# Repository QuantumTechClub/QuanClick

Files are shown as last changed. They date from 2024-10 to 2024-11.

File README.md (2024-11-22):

Heading Title Image, QuanClick logo on the left, Quantum Technology Club logo on the right

## Table of Contents
1. [Getting Started](#getting-started)
   - [Quickstart](#quickstart-i-dont-want-to-read-tutorials)
   - [In More Detail](#in-more-detail)
     - [Setting up your development environment](#setting-up-your-development-environment)
     - [Programming your QuanClick](#programming-your-quanclick)
2. [Customization](#customization)

## What
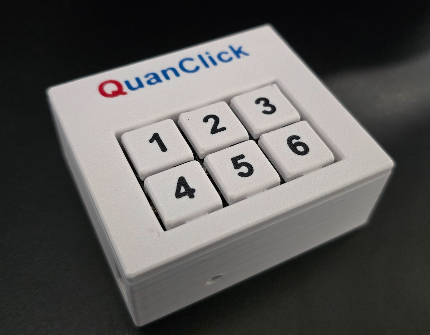
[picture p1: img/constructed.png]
A photograph of a completed QuanClick unit


QuanClick is a six-button macro keyboard (and HID) device, designed to be low cost, easy to assemble, and easy to customize.

## Why
To support and promote S.T.E.A.M. (Science, Technology, Engineering, Arts, and Mathematics) education, experimentation, and exposure in the community.

## Who
Designed, prototyped, and produced by members of [Quantum Technology Club](https://quantumtech.club/)

## Getting Started

All files, examples, and documentation assume development on a [Raspberry Pi Pico v2](https://www.raspberrypi.com/products/raspberry-pi-pico-2/) development board.

Source code is in the '/src/' folder. Each `code.py` should have an accompanying `README.md`.

### Quickstart (I don't want to read tutorials)

1. Clone or download this repository
2. Boot the Raspberry Pi Pico 2 into firmware loading mode (see detailed instructions below)
3. Copy the CircuitPython firmware onto the drive that appears from: `/board_files/firmware_pico_v2/adafruit-circuitpython-raspberry_pi_pico2-en_GB-9.2.1.uf2`
4. Wait for the Pico to reboot and show up again
5. Copy the contents of `board_files/lib` to the Pico 2 
6. Copy the basic example from `src/code.py` into the root of the drive that shows up after the reboot

### In More Detail

#### Setting up your development environment

1. Install Thonny IDE:
   - Download and install Thonny from [https://thonny.org/](https://thonny.org/)
   - Thonny provides a user-friendly interface for programming and interacting with your Raspberry Pi Pico

2. Prepare your Raspberry Pi Pico:
   - Connect your Pico to your computer using a micro-USB cable
   - Hold down the BOOTSEL button on the Pico while plugging it in to enter firmware loading mode

3. Install CircuitPython:
   - Download the CircuitPython UF2 file for Raspberry Pi Pico 2 from the `/board_files/firmware_pico_v2/` directory in this repository
   - Drag and drop the UF2 file onto the RPI-RP2 drive that appears when the Pico is in firmware loading mode
   - The Pico will reboot and appear as a new drive named CIRCUITPY

4. Set up the required libraries:
   - Copy the contents of the `board_files/lib` directory from this repository to the `lib` folder on your CIRCUITPY drive

#### Programming your QuanClick

1. Open Thonny IDE
2. In Thonny, go to "Tools" > "Options" > "Interpreter" and select "CircuitPython (generic)" as the interpreter
3. Click on "Select port" and choose the port corresponding to your Raspberry Pi Pico
4. Open the `src/code.py` file from this repository in Thonny
5. Click the "Run" button or press F5 to run the code on your Pico

For more detailed information on getting started with CircuitPython on Raspberry Pi Pico, refer to these Adafruit guides:
- [Getting Started with Raspberry Pi Pico and CircuitPython](https://learn.adafruit.com/getting-started-with-raspberry-pi-pico-circuitpython/overview)
- [CircuitPython Programming Basics](https://learn.adafruit.com/getting-started-with-raspberry-pi-pico-circuitpython/circuitpython-programming-basics)

## Customization

To customize your QuanClick:

1. Open the `src/code.py` file in Thonny
2. Modify the `button_actions` dictionary to change the behavior of each button
3. Use the appropriate `Keycode` values from the `adafruit_hid.keycode` module for keyboard actions
4. For mouse actions, specify the movement amounts or button to click

Example customization:
```python
button_actions = {
    0: {"type": "keyboard", "action": [Keycode.CTRL, Keycode.C]},  # Copy
    1: {"type": "keyboard", "action": [Keycode.CTRL, Keycode.V]},  # Paste
    2: {"type": "mouse_move", "action": (0, -10)},  # Move mouse up
    3: {"type": "mouse_move", "action": (0, 10)},   # Move mouse down
    4: {"type": "mouse_click", "action": Mouse.LEFT_BUTTON},
    5: {"type": "mouse_click", "action": Mouse.RIGHT_BUTTON}
}

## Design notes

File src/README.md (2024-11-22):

# QuanClick: Basic Implementation

The accompanying `quanclick.py` implements a custom input device controller using CircuitPython on a microcontroller board. It allows for the creation of a programmable keyboard and mouse interface with customizable button actions.

## Table of Contents

1. [Hardware Requirements](#hardware-requirements)
2. [Software Dependencies](#software-dependencies)
3. [Code Overview](#code-overview)
4. [Button Configuration](#button-configuration)
5. [Main Loop](#main-loop)
6. [Functions](#functions)
7. [Usage](#usage)
8. [Customization](#customization)

## Hardware Requirements

- Microcontroller board compatible with CircuitPython (e.g., Raspberry Pi Pico)
- 6 push button module
- Appropriate wiring

## Software Dependencies

The code relies on the following CircuitPython libraries:

- `board`
- `digitalio`
- `usb_hid`
- `adafruit_hid.keyboard`
- `adafruit_hid.keycode`
- `adafruit_hid.mouse`

Ensure these libraries are installed on your microcontroller. (See Main `README.md`)

## Code Overview

The code sets up a custom input device that can perform keyboard and mouse actions based on button presses. It uses the CircuitPython USB HID (Human Interface Device) functionality to emulate keyboard and mouse inputs.

## Button Configuration

The code configures 6 buttons connected to the following GPIO pins:

- Button 0: GP0
- Button 1: GP2
- Button 2: GP4
- Button 3: GP1
- Button 4: GP3
- Button 5: GP5

Each button is set up as an input with a pull-up resistor.

## Main Loop

The main loop continuously checks the state of each button. When a button state change is detected (from pressed to released), it triggers the corresponding action defined in the `button_actions` dictionary.

## Functions

### `perform_keyboard_action(action)`

Executes a keyboard action, which can be a single key press or a combination of keys.

### `perform_mouse_move(movement)`

Moves the mouse cursor by the specified x and y amounts.

### `perform_mouse_click(button)`

Performs a mouse click using the specified button.

## Button Actions

The `button_actions` dictionary defines the actions for each button:

- Button 0: Types "STE" with shift held for "S"
- Button 1: Types "STEE"
- Button 2: Opens File Explorer (Windows + E)
- Button 3: Moves the mouse cursor 20 pixels to the right
- Button 4: Moves the mouse cursor 20 pixels to the left
- Button 5: Performs a left mouse click

## Usage

1. Connect the buttons to the specified GPIO pins on your microcontroller.
2. Upload the code to your microcontroller (renaming to `code.py` if you wish it to auto-run)
3. Connect the microcontroller to a computer via USB.
4. Press the buttons to trigger the corresponding actions.

## Customization

To customize the button actions:

1. Modify the `button_actions` dictionary in the code.
2. For keyboard actions, use the appropriate `Keycode` values from the `adafruit_hid.keycode` module.
3. For mouse actions, specify the movement amounts or button to click.

Example:
```python
button_actions = {
    0: {"type": "keyboard", "action": [Keycode.A, Keycode.B, Keycode.C]},
    1: {"type": "mouse_move", "action": (0, -10)},  # Move up
    2: {"type": "mouse_click", "action": Mouse.RIGHT_BUTTON}
}

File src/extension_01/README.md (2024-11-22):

# QuanClick: Strings and Media Controls

## Table of Contents
1. [Overview](#overview)
2. [Features](#features)
3. [Hardware Requirements](#hardware-requirements)
4. [Software Dependencies](#software-dependencies)
5. [Configuration](#configuration)
6. [Functions](#functions)
7. [Main Loop](#main-loop)
8. [Usage](#usage)
9. [Customization](#customization)

## Overview

This project implements a customizable Human Interface Device (HID) using CircuitPython on a microcontroller board. It allows for the creation of a programmable keyboard, mouse, and consumer control interface with customizable button actions.

## Features

- Support for 6 hardware buttons
- Customizable button actions
    - Sends Keyboard input (individual keys and strings)
    - Sends Mouse movement and clicks
    - Sends Consumer control actions (e.g., media controls)
    - Random delays for keyboard input to mimic human typing

## Hardware Requirements

- Microcontroller board compatible with CircuitPython (e.g., Raspberry Pi Pico)
- 6 push buttons
- Appropriate connectors and wiring

## Software Dependencies

The code relies on the following CircuitPython libraries:

- `board`
- `digitalio`
- `usb_hid`
- `adafruit_hid.keyboard`
- `adafruit_hid.keyboard_layout_us`
- `adafruit_hid.keycode`
- `adafruit_hid.mouse`
- `adafruit_hid.consumer_control`
- `adafruit_hid.consumer_control_code`

Ensure these libraries are installed on your microcontroller.

## Configuration

The configuration section defines constants and button actions:

- `KEYBOARD_CHAR_DELAY_MIN` and `KEYBOARD_CHAR_DELAY_MAX`: Define the range for random delays between keystrokes.
- `CCC_PLAY_PAUSE_TOGGLE`: A custom consumer control code for play/pause toggle.
- `button_pins`: GPIO pins for the buttons.
- `button_actions`: A dictionary defining actions for each button.

## Functions

### `perform_keyboard_action(action)`

Sends keyboard actions, including single keys, key sequences, and key combinations.

### `perform_keyboard_string(string)`

Types a string with random delays between characters to mimic human typing.

### `perform_mouse_move(movement)`

Moves the mouse cursor by the specified x and y amounts.

### `perform_mouse_click(button)`

Performs a mouse click using the specified button.

### `perform_consumer_control_action(action)`

Sends a consumer control action, such as media controls or system functions.

## Main Loop

The main loop continuously checks the state of each button. When a button state change is detected (from pressed to released), it triggers the corresponding action defined in the `button_actions` dictionary.

## Usage

1. Connect the buttons to the specified GPIO pins on your microcontroller.
2. Customize the `button_actions` dictionary to define desired actions for each button.
3. Upload the code to your microcontroller.
4. Connect the microcontroller to a computer via USB.
5. Press the buttons to trigger the corresponding actions.

## Customization

To customize button actions, modify the `button_actions` dictionary in the configuration section. Each action is defined by a type and an action value. Supported types include:

- `"keyboard"`: Send keyboard key presses
- `"keyboard_string"`: Type a string
- `"consumer_control"`: Send consumer control actions
- `"mouse_move"`: Move the mouse cursor
- `"mouse_click"`: Perform mouse clicks

Example customization:

```python
button_actions = {
    1: {"type": "keyboard", "action": [Keycode.CTRL, Keycode.C]},  # Copy
    2: {"type": "keyboard_string", "action": "Hello, World!"},     # Type a string
    3: {"type": "consumer_control", "action": ConsumerControlCode.VOLUME_INCREMENT},  # Volume up
    4: {"type": "mouse_move", "action": (0, -10)},  # Move mouse up
    5: {"type": "mouse_click", "action": Mouse.LEFT_BUTTON},  # Left click
    6: {"type": "consumer_control", "action": CCC_PLAY_PAUSE_TOGGLE}  # Custom media control
}

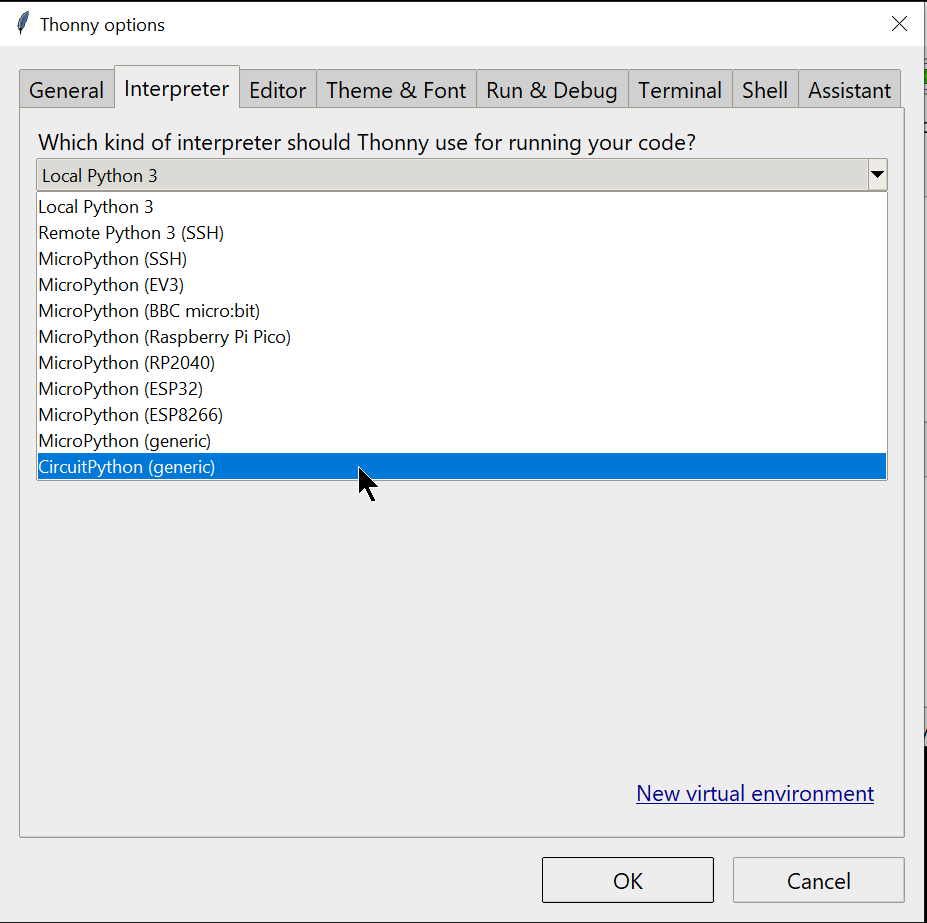
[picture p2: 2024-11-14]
img/select_interpreter.png

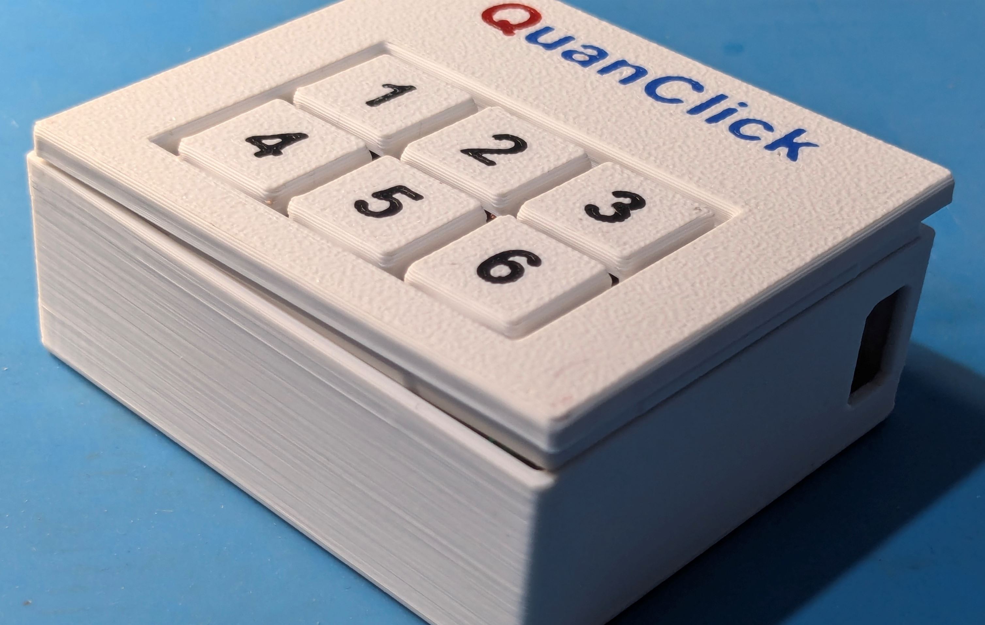
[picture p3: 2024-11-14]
img/close_lid.jpg

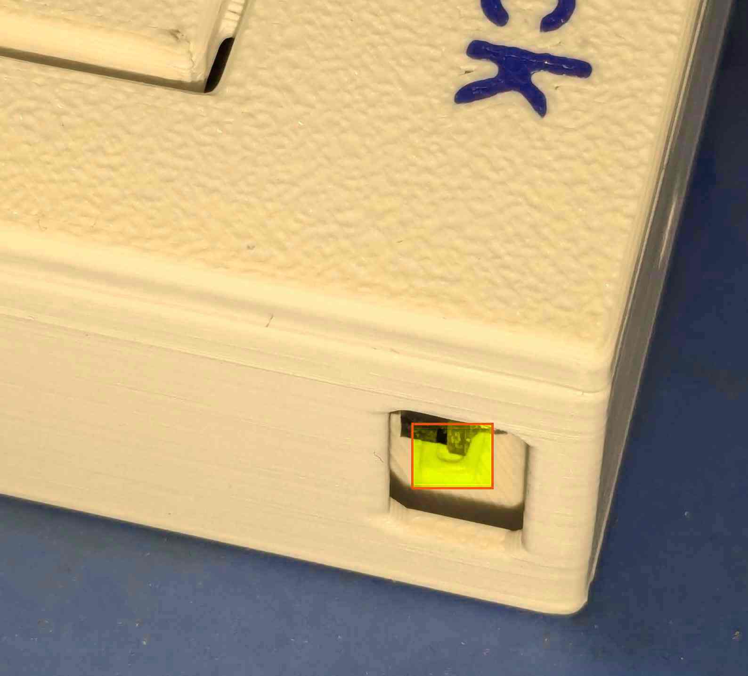
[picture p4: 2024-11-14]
img/check_alignment.jpg

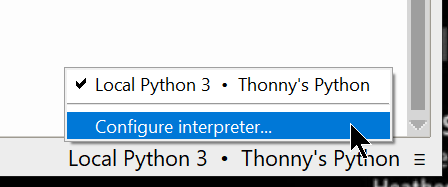
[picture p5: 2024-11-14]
img/lower_thonny_menu.png

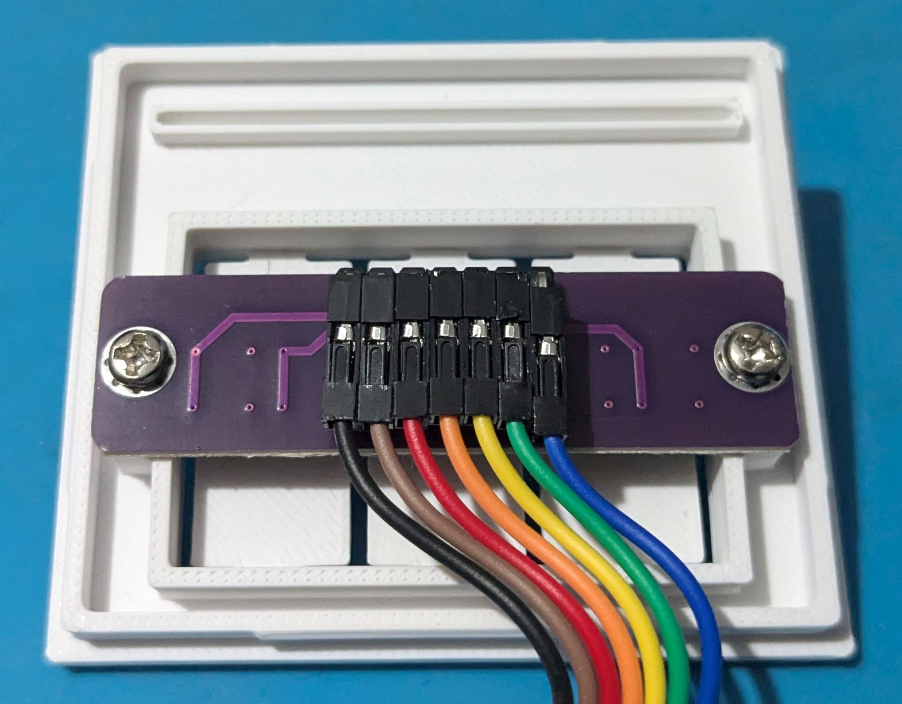
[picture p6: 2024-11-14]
img/connect_buttons.jpg

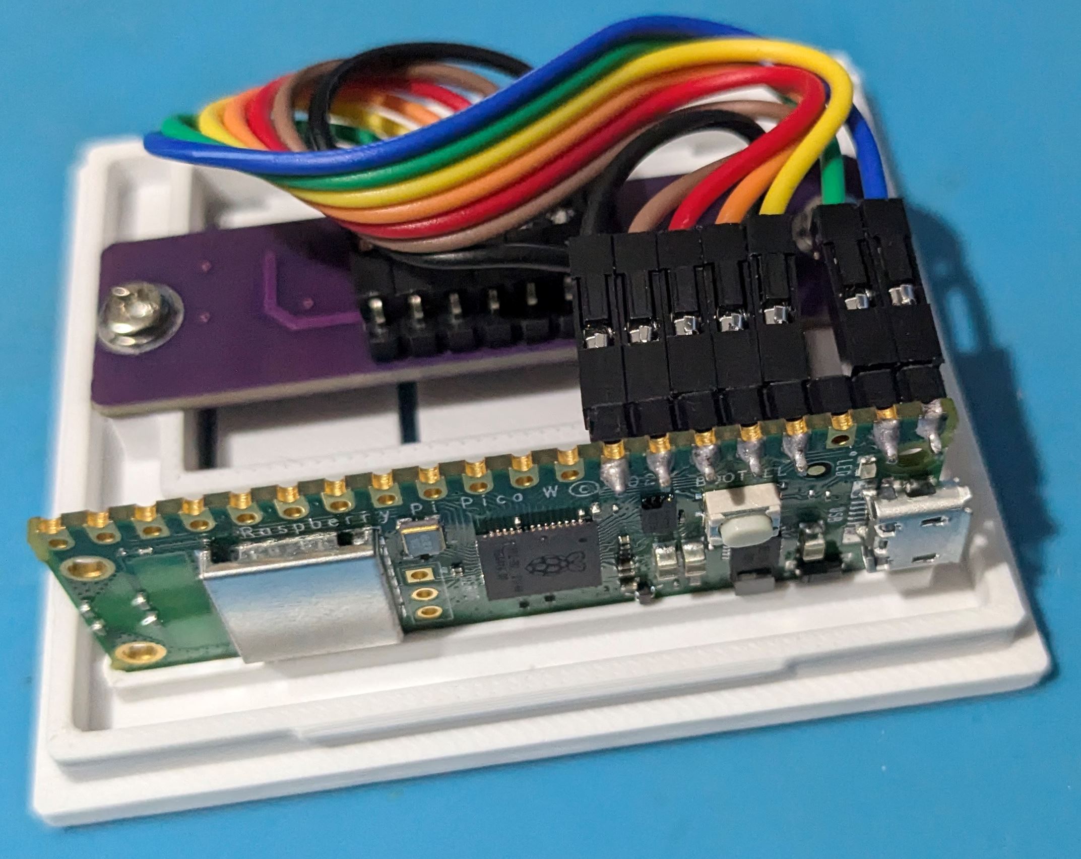
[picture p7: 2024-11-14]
img/connect_pico.jpg

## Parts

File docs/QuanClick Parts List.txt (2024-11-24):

QuanClick Parts list and example suppliers

6 button module
https://www.aliexpress.com/item/1005005656486739.html

Dupont 10cm female to female jumper wire set
https://www.aliexpress.com/item/1005007072081464.html

M3x8mm Philips self tapping machine screws
https://www.aliexpress.com/item/1005004166837447.html

2.54mm header straight and right angle
https://www.aliexpress.com/item/32796117265.html

Raspberry Pi Pico 2
https://shop.pimoroni.com/products/raspberry-pi-pico-2?variant=42096955424851

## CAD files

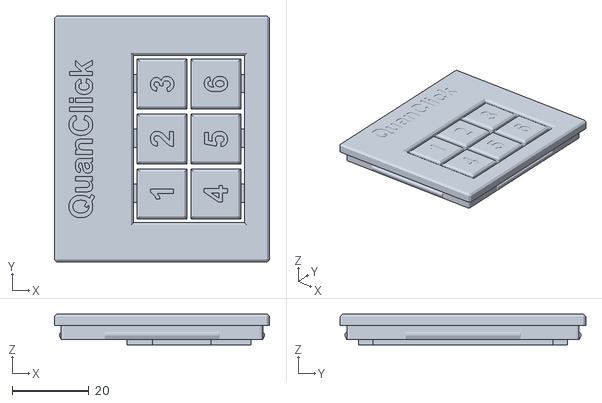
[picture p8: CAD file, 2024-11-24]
cad/QuanClick_Lid.stl
56.0 x 64.0 x 8.00

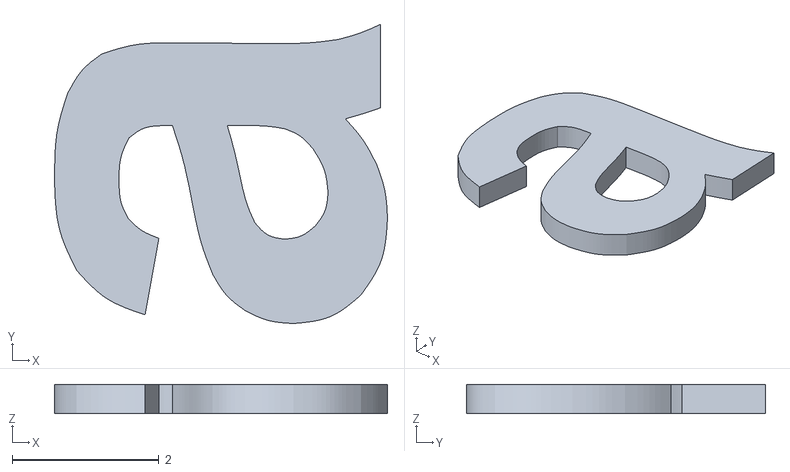
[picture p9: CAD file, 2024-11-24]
cad/QuanClick_LetA.stl
4.54 x 4.08 x 0.4

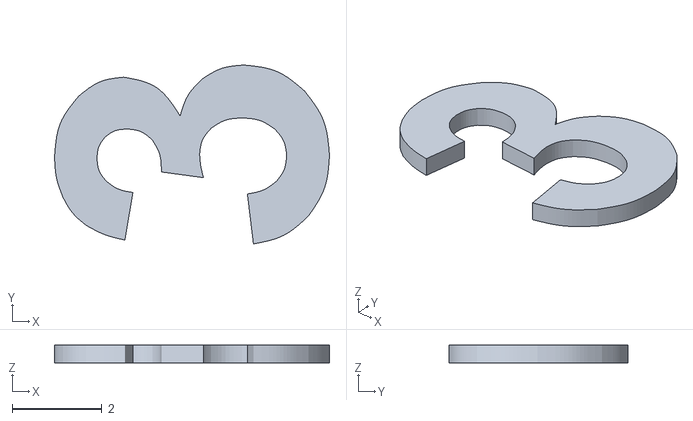
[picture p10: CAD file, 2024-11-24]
cad/QuanClick_Num3.stl
6.13 x 3.99 x 0.4

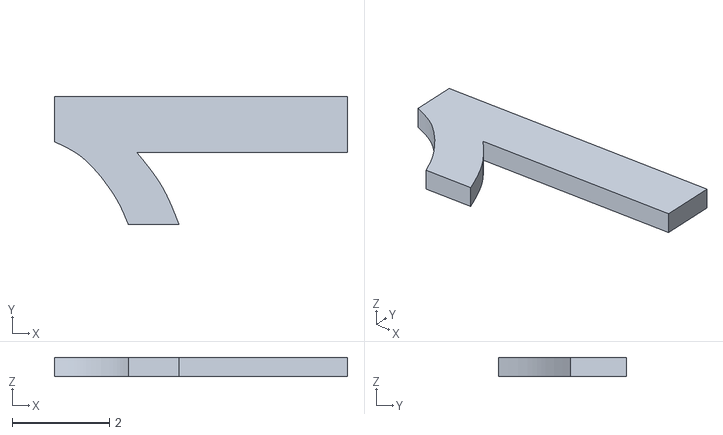
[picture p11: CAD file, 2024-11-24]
cad/QuanClick_Num1.stl
6.02 x 2.64 x 0.4

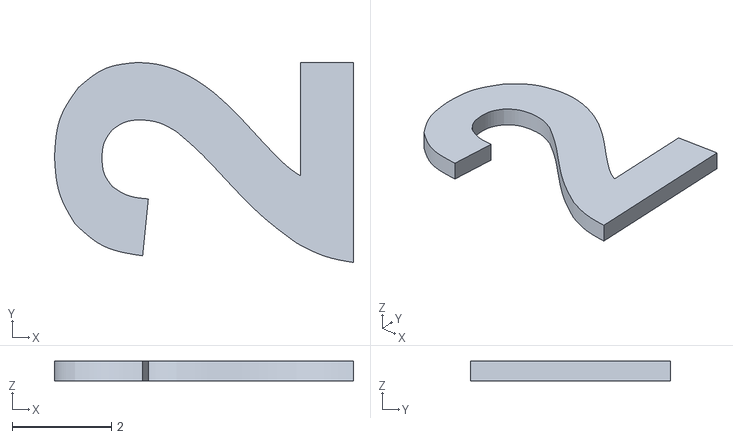
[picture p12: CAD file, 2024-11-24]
cad/QuanClick_Num2.stl
6.02 x 4.03 x 0.4

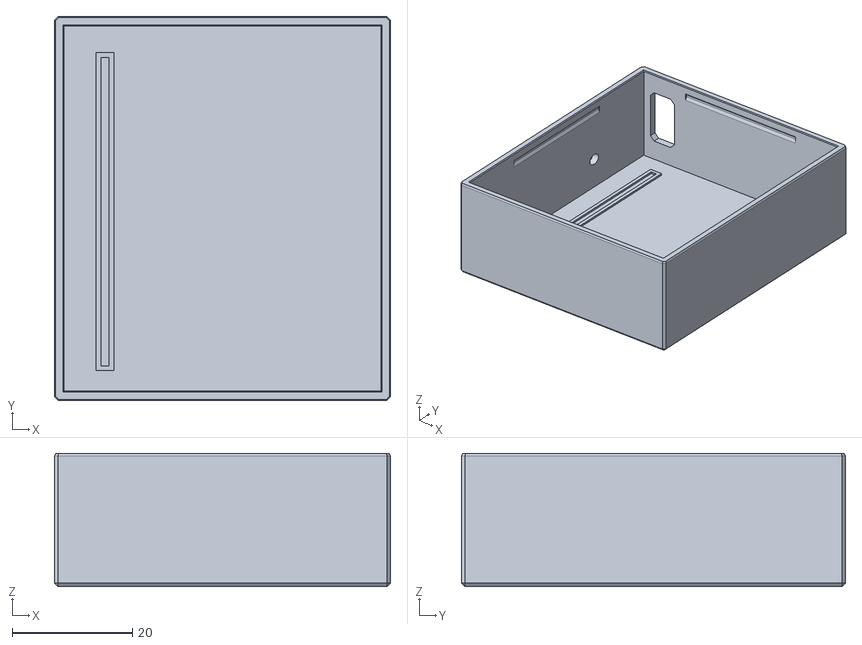
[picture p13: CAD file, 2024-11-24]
cad/QuanClick_Base.stl
56.0 x 64.0 x 22.2

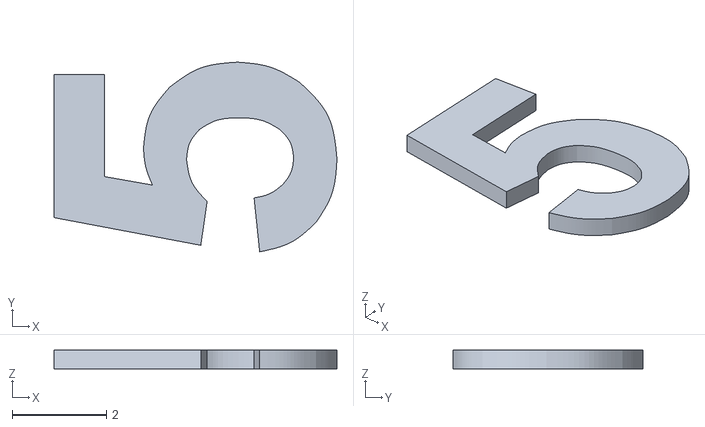
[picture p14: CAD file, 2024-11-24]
cad/QuanClick_Num5.stl
6.02 x 4.04 x 0.4

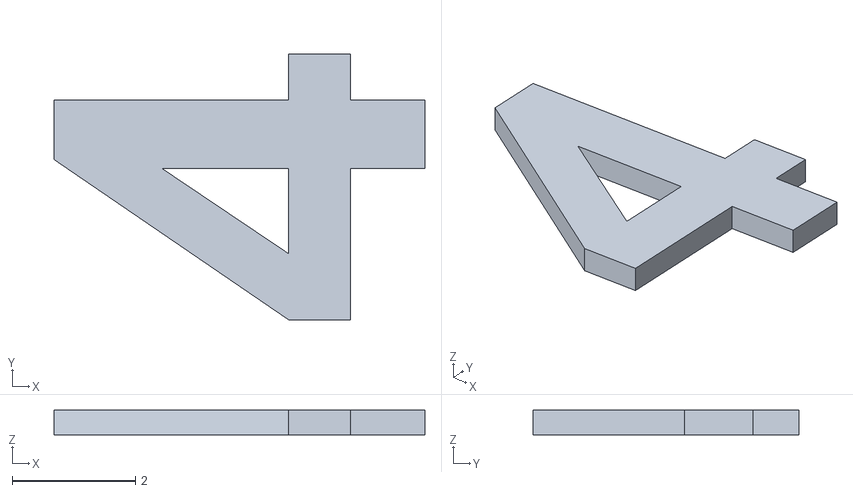
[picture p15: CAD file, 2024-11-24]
cad/QuanClick_Num4.stl
6.02 x 4.31 x 0.4

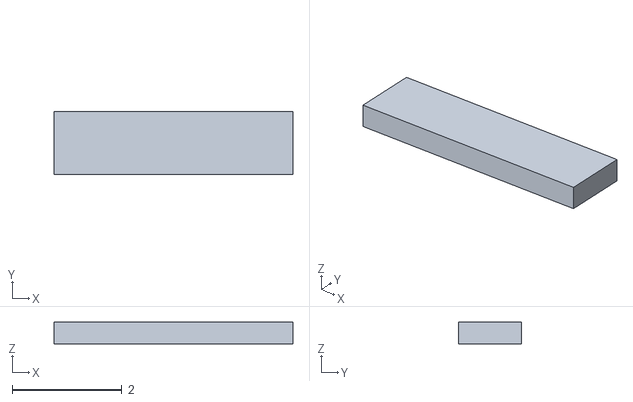
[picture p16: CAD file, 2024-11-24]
cad/QuanClick_LetI.stl
4.35 x 1.15 x 0.4

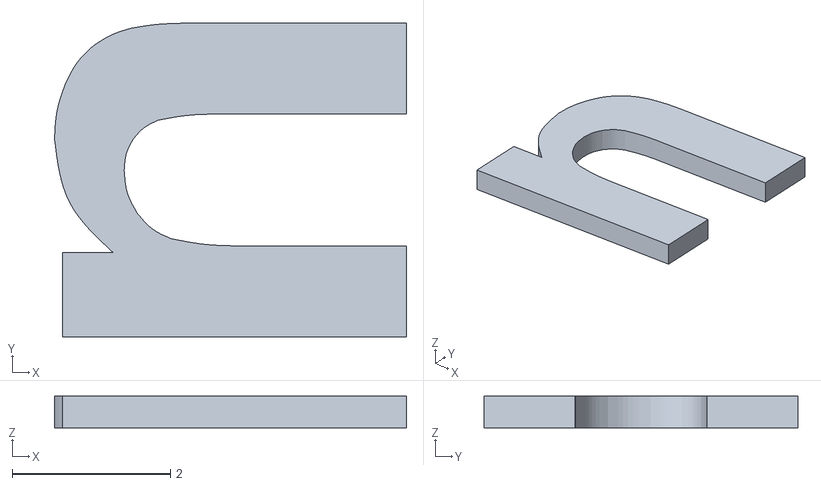
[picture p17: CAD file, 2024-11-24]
cad/QuanClick_LetN.stl
4.44 x 3.96 x 0.4

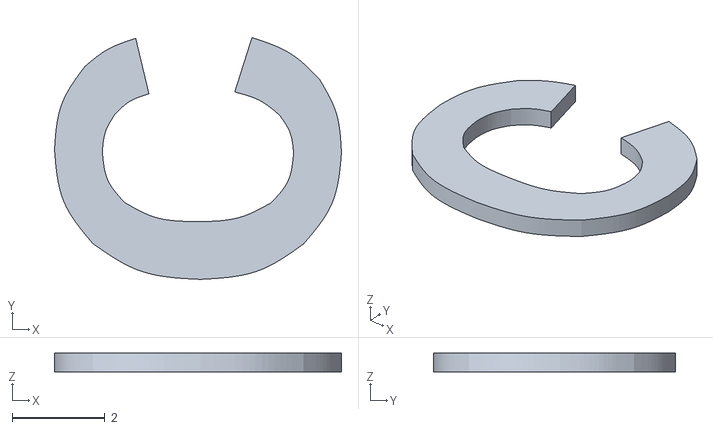
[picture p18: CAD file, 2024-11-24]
cad/QuanClick_LetCcap.stl
6.20 x 5.23 x 0.4

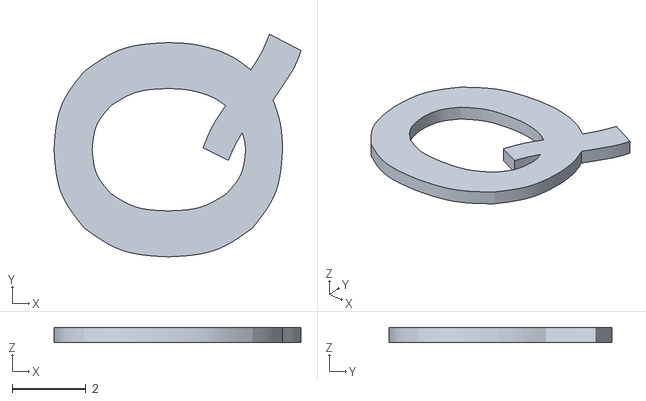
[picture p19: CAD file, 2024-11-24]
cad/QuanClick_LetQcap.stl
6.70 x 6.05 x 0.4

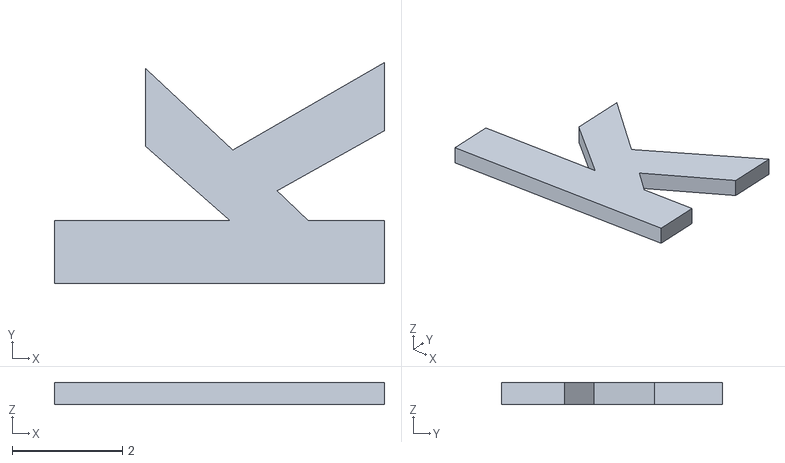
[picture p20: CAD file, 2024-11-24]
cad/QuanClick_LetK.stl
6.00 x 4.02 x 0.4

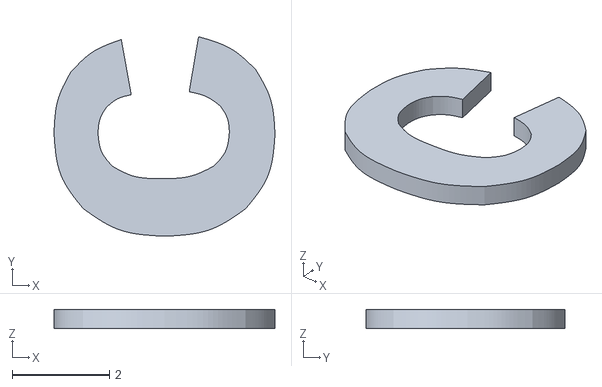
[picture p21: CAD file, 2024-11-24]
cad/QuanClick_LetC.stl
4.54 x 4.10 x 0.4

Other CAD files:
cad/QuanClick_Num6.stl
cad/QuanClick_LetL.stl
cad/QuanClick_LetU.stl
cad/QuanClick_LetIdot.stl

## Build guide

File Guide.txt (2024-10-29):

QuanClick

Setup the Pi Pico
Plug in Pi Pico
	Windows will instal a com port
	Unplug the Pi Pico
Put the Pico into UF2 download mode
	Hold down the BOOT/SEL button on the Pi Pico
	Plug in Pi Pico
	Windows will open an explorer window
Adding CircuitPython to the Pi Pico
Download the CircuitPython 9.1.4 .UF2 file
	https://circuitpython.org/board/raspberry_pi_pico/
	drag and drop the download into the Pi Pico root folder

Donload and install Thonny with Python
Thonny website
https://thonny.org/
Github download for portable version
https://github.com/thonny/thonny/releases/download/v4.1.6/thonny-py38-4.1.6-windows-portable.zip
Extract all to C:\Users\{user_name}\Thonny
Run Thonny.exe
	Language: English (UK)
	Initial Settings: Raspberry Pi (simple)

Click on the lower Thonny menu
	Configure interpreter...

Select an interpreter
	CircuitPython (generic)
	Select OK
Thonny should detect com port and show in the lower menu

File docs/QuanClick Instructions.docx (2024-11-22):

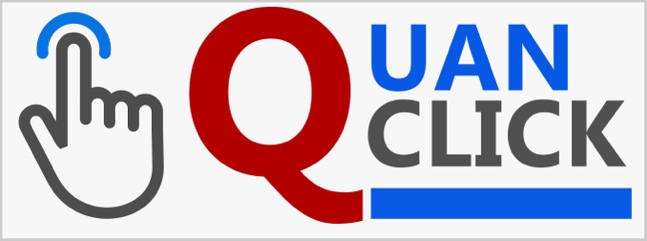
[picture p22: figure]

What is QuanClick?

QuanClick is a user-configurable mouse and keyboard code generator.

It reacts to presses from a 6-button keypad and sends sequences of mouse, or keyboard, control codes over USB just like a real mouse or keyboard would do.

Because you can send sequences of codes (or macros) you can replace many mouse or keyboard actions with just one button press.

For example, you can program one button to type out your email address with just one click.

QuanClick uses a Raspberry Pi Pico 2 microcontroller that we will refer to as a ‘Pico’ throughout this document.

If you choose to use other variants of Pico (such as the original Pico 1) you will need to substitute the UF2 for the board you are using.

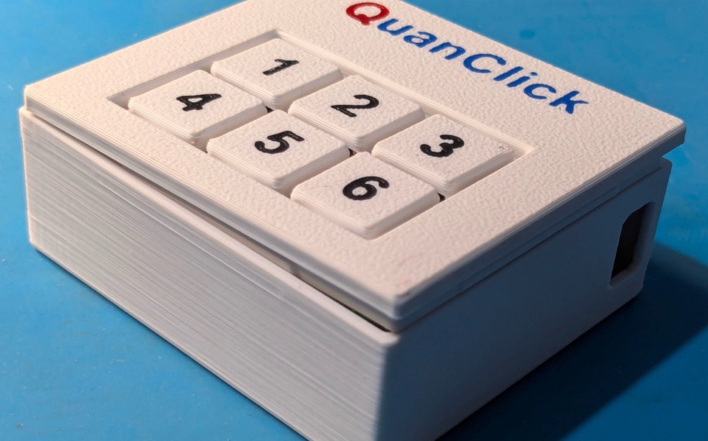
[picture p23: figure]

QuanClick was designed and built by members of the
Quantum Technology Club

For further details about the Quantum Technology Club, please visit

www.quantumtech.club

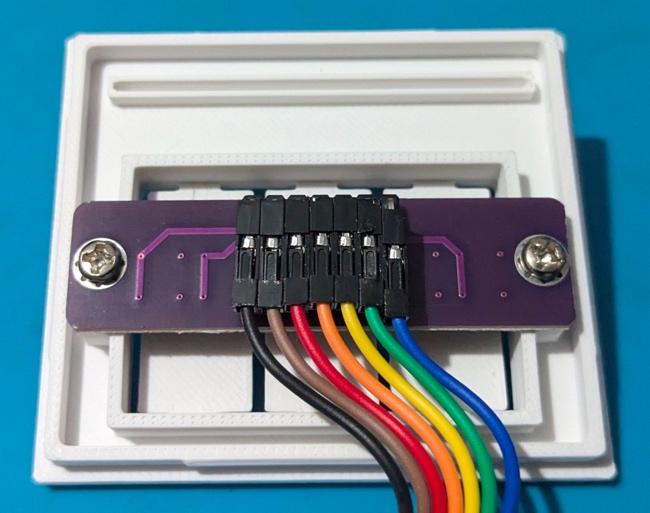
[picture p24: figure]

Assembly Instructions Connect the cables to the buttons Attach the pins from one end of the multiway cable to the pin header on the keypad. Your multiway cable may not have the identically coloured wires as in this photo - that’s not important, just that they are all different colours so you can easily identify them either end. Just make sure all the connectors are pushed in fully. The connection to the left (in this picture the pin with the black wire) is the common connection, the other 6 are for each of the buttons.

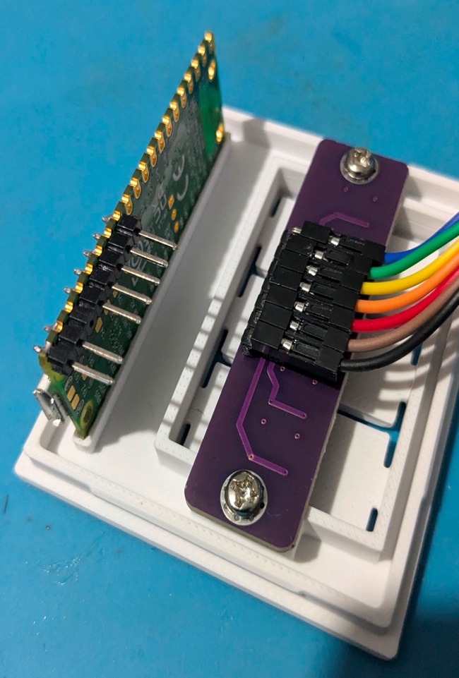
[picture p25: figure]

Insert the Pico into the case Carefully insert the Pico into the printed slot as shown in the photo below. Insert one corner first then work the other corner in by pushing down on the edge of the board. It is a firm fit but be careful not to damage the board.

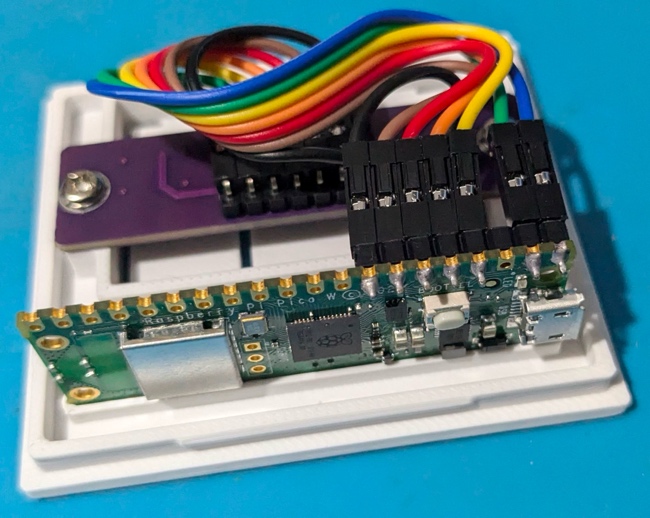
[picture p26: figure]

Connect the cables to the Pico Connect the wires to the Pico as shown in the photo matching your appropriate colours between button board and Pico. Note the gap between connection 2 and 3. Check that the common wire on the button board is connected to the 7th end connection pin on the Pico.

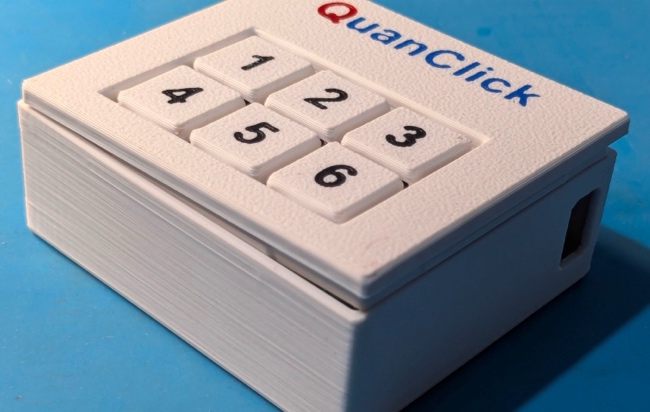
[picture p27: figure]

Close the lid Fit the lid onto the box by aligning the left (non-USB socket) side of the lid first.

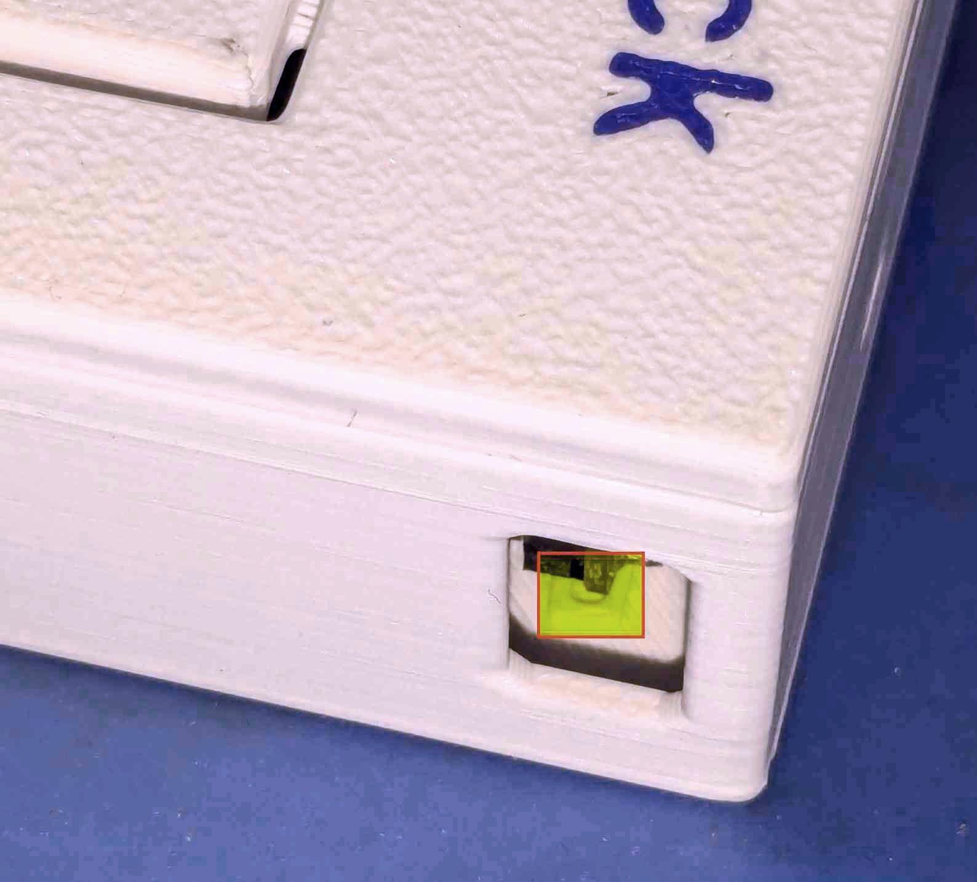
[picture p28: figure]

Check board alignment Look through the hole in the case and check that the bottom of the Pico board is matched into the slot in the base of the case as shown in the photograph. If the board is not aligned, then lift the lid and gently move the Pico in its lid slot and try again. Once the board aligns well then click the lid down.

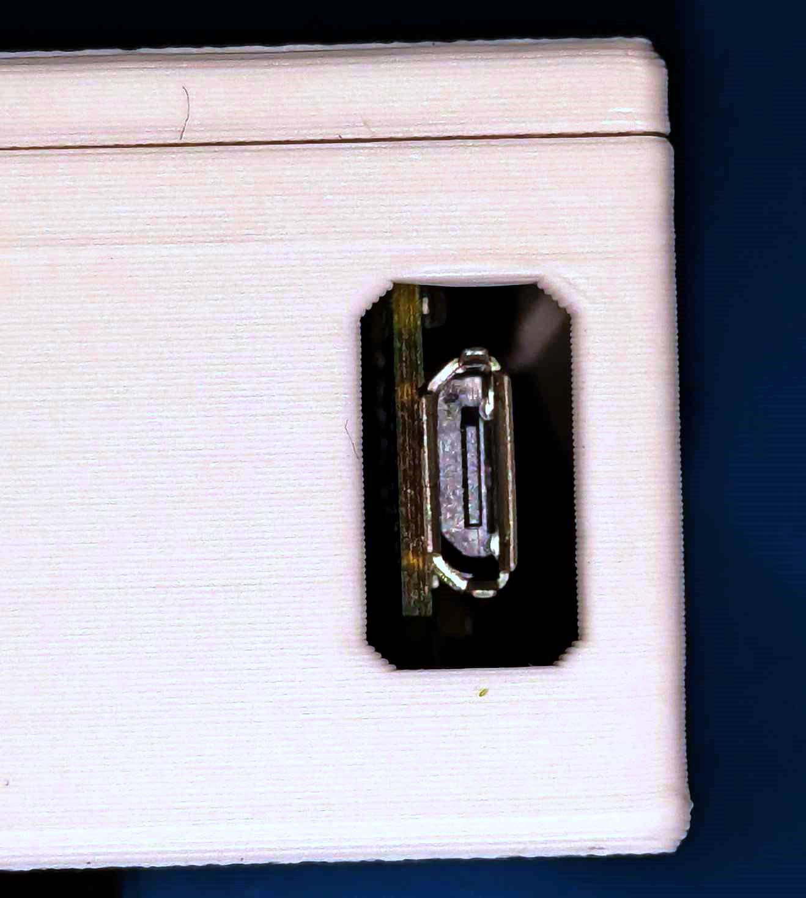
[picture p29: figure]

Check Micro-USB alignment Look through the hole in the case and check that the Micro-USB socket sits square in the aperture. Insert the Micro-USB cable into the Pico. Assembly is now complete.

# Configuring the Pico

## Plug in the Pico into your computer

Once you plug your Pico into your computer, Windows will install the device drivers.

Once installed, unplug the Pico.

## Put the Pico into UF2 download mode

Hold down the BOOT/SEL button on the Pico using a small screwdriver through the hole in the case and, whilst keeping the button pressed, plug the Pico into your computer.

Once plugged in, release the BOOT/SEL button.

Windows should open an Explorer (file manager) window (if not open an explorer window). Navigate to “My Computer” where you should see a new drive.

The Pico acts like a USB memory stick and this is how you add your programs and also the firmware to make the Pico operate – we need to install the correct version of firmware to make QuanClick work.

## Install Circuit Python

Download the latest stable CircuitPython .UF2 file (v9.2.1 at time of writing) from …

https://circuitpython.org/board/raspberry_pi_pico2/

Drag and drop the downloaded file into the Pico root folder in the Explorer window that opened earlier.

The Pico should accept the file, recognise it as a firmware update, install it automatically and reboot itself. Windows will detect this reboot and momentarily disconnect the drive then reconnect it. The Pico drive should now show with the updated firmware files.

Configuration is now complete.

# Setting up Thonny with Python

## Download from the Thonny web site

Download Thonny with Python from the Thonny web site at …

https://thonny.org

When the page loads, you will see the links for the computer you are using in the top right corner (as highlighted in the image below).

## Download from GitHub download for the portable version

The portable version of Thonny can be downloaded from the GitHub web site at …

https://github.com/thonny/thonny/releases/download/v4.1.6/thonny-py38-4.1.6-windows-portable.zip

Extract the contents of the zip file to C:\Users\{user_name}\Thonny

## Install Thonny

Run Thonny.exe using the following settings …

Language: English (UK)

Initial Settings: Raspberry Pi (simple)

Once Thonny is up-and-running …

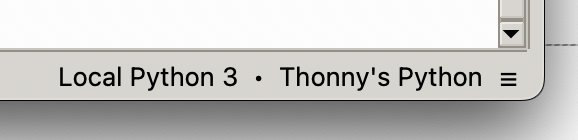
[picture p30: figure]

Click in the Thonny menu located in the lower right corner of the window (it’s highlighted in red).

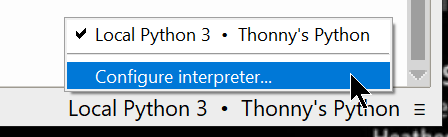
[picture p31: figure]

When the menu pops up, select Configure interpreter …

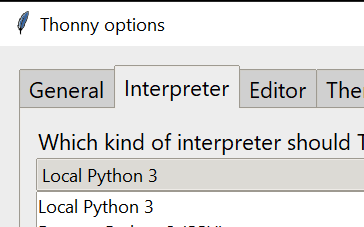
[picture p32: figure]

When the Thonny Options dialog box appears, click over the Interpreter tab (if it is not already selected) …
… and then select the Circuit Python (generic) programming language interpreter. Click over the [OK] button. Thonny should detect your Pico and the ‘com port’ it is connected to and display it in the bottom right corner of the Thonny window.

Your computer is now set up with Thonny.

# Programming the Pico

## QuanClick project files

You can download the source code and all the support files from …

https://github.com/QuantumTechClub/QuanClick

## Adding the libraries

In the board_files/lib directory there is a adafruit_hid directory that contains library files used in our project

That entire directory and its contents need to be copied to the lib directory on the Pico device.

Drag and drop the entire folder across.

## Open the code in Thonny

Open the src/quanclick.py python file in Thonny …

File > Open > This computer

… and then navigate to where you downloaded the file to and click over the [Open] button.

Run the script …

Run > Run the script

## Changing the macros

The code can be modified to set personal actions for any key, some examples pre-exist in the source code.

The definitions are listed in the ‘button_actions’ array at line 27 in the code.

There are 3 types of actions – keyboard, mouse_move and mouse_click.

- The keyboard actions contain Keycode types which are encoded codes for each key and special keys like [SHIFT] and [WINDOWS].
- The mouse_move actions contain an x,y co-ordinate move.
- The mouse_click actions contain Mouse types like [LEFT_BUTTON].

The Appendix contains the codes you can use.

## Installing onto the Pico

Once you are happy with the definition changes then you need to save the python file onto the Pico

- Select File > Save As
- Choose to save the file on the device

## Getting the Pico to autorun the file

To use the Pico in stand alone (ie without running the application via Thonny) we need to change the contents of the default file code.py on the Pico.

- Open the code.py file on the Pico
- Change the contents of that file to read
  - import quanclick
- Save the file back to the Pico

The quanclick code will now autorun

# Appendix

## Keycodes

Keycode | Value | Function
A | 4 | a and A
ALT | 226 | Alias for LEFT_ALT; Alt is also known as Option (Mac)
APPLICATION | 101 | also known as the Menu key (Windows)
B | 5 | b and B
BACKSLASH | 49 | \ and
BACKSPACE | 42 | Delete backward (Backspace)
C | 6 | c and C
CAPS_LOCK | 57 | Caps Lock
COMMA | 54 | , and <
COMMAND | 227 | Labelled as Command on Mac keyboards, with a clover glyph
CONTROL | 224 | Alias for LEFT_CONTROL
D | 7 | d and D
DELETE | 76 | Delete forward
DOWN_ARROW | 81 | Move the cursor down
E | 8 | e and E
EIGHT | 37 | 8 and *
END | 77 | End (often moves to end of line)
ENTER | 40 | Enter (Return)
EQUALS | 46 | =` and ``+
ESCAPE | 41 | Escape
F | 9 | f and F
F1 | 58 | Function key F1
F10 | 67 | Function key F10
F11 | 68 | Function key F11
F12 | 69 | Function key F12
F13 | 104 | Function key F13 (Mac)
F14 | 105 | Function key F14 (Mac)
F15 | 106 | Function key F15 (Mac)
F16 | 107 | Function key F16 (Mac)
F17 | 108 | Function key F17 (Mac)
F18 | 109 | Function key F18 (Mac)
F19 | 110 | Function key F19 (Mac)
F2 | 59 | Function key F2
F20 | 111 | Function key F20
F21 | 112 | Function key F21
F22 | 113 | Function key F22
F23 | 114 | Function key F23
F24 | 115 | Function key F24
F3 | 60 | Function key F3
F4 | 61 | Function key F4
F5 | 62 | Function key F5
F6 | 63 | Function key F6
F7 | 64 | Function key F7
F8 | 65 | Function key F8
F9 | 66 | Function key F9
FIVE | 34 | 5 and %
FORWARD_SLASH | 56 | / and ?
FOUR | 33 | 4 and $
G | 10 | g and G
GRAVE_ACCENT | 53 | ` and ~
GUI | 227 | Alias for LEFT_GUI; GUI is also known as the Windows key or Command (Mac)
H | 11 | h and H
HOME | 74 | Home (often moves to beginning of line)
I | 12 | i and I
INSERT | 73 | Insert
J | 13 | j and J
K | 14 | k and K
KEYPAD_ASTERISK | 85 | Keypad *
KEYPAD_BACKSLASH | 100 | Keypad \ and | (Non-US)
KEYPAD_EIGHT | 96 | Keypad 8 and Up Arrow
KEYPAD_ENTER | 88 | Keypad Enter
KEYPAD_EQUALS | 103 | Keypad = (Mac)
KEYPAD_FIVE | 93 | Keypad 5
KEYPAD_FORWARD_SLASH | 84 | Keypad /
KEYPAD_FOUR | 92 | Keypad 4 and Left Arrow
KEYPAD_MINUS | 86 | Keypad -
KEYPAD_NINE | 97 | Keypad 9 and PgUp
KEYPAD_NUMLOCK | 83 | Num Lock (Clear on Mac)
KEYPAD_ONE | 89 | Keypad 1 and End
KEYPAD_PERIOD | 99 | Keypad . and Del
KEYPAD_PLUS | 87 | Keypad +
KEYPAD_SEVEN | 95 | Keypad 7 and Home
KEYPAD_SIX | 94 | Keypad 6 and Right Arrow
KEYPAD_THREE | 91 | Keypad 3 and PgDn
KEYPAD_TWO | 90 | Keypad 2 and Down Arrow
KEYPAD_ZERO | 98 | Keypad 0 and Ins
L | 15 | l and L
LEFT_ALT | 226 | Alt modifier left of the spacebar
LEFT_ARROW | 80 | Move the cursor left
LEFT_BRACKET | 47 | [ and {
LEFT_CONTROL | 224 | Control modifier left of the spacebar
LEFT_GUI | 227 | GUI modifier left of the spacebar
LEFT_SHIFT | 225 | Shift modifier left of the spacebar
M | 16 | m and M
MINUS | 45 | -` and ``_
N | 17 | n and N
NINE | 38 | 9 and (
O | 18 | o and O
ONE | 30 | 1 and !
OPTION | 226 | Labelled as Option on some Mac keyboards
P | 19 | p and P
PAGE_DOWN | 78 | Go forward one page
PAGE_UP | 75 | Go back one page
PAUSE | 72 | Pause (Break)
PERIOD | 55 | . and >
POUND | 50 | # and ~ (Non-US keyboard)
POWER | 102 | Power (Mac)
PRINT_SCREEN | 70 | Print Screen (SysRq)
Q | 20 | q and Q
QUOTE | 52 | ' and "
R | 21 | r and R
RETURN | 40 | Alias for ENTER
RIGHT_ALT | 230 | Alt modifier right of the spacebar
RIGHT_ARROW | 79 | Move the cursor right
RIGHT_BRACKET | 48 | ] and }
RIGHT_CONTROL | 228 | Control modifier right of the spacebar
RIGHT_GUI | 231 | GUI modifier right of the spacebar
RIGHT_SHIFT | 229 | Shift modifier right of the spacebar
S | 22 | s and S
SCROLL_LOCK | 71 | Scroll Lock
SEMICOLON | 51 | ; and :
SEVEN | 36 | 7 and &
SHIFT | 225 | Alias for LEFT_SHIFT
SIX | 35 | 6 and ^
SPACE | 44 | Alias for SPACEBAR
SPACEBAR | 44 | Spacebar
T | 23 | t and T
TAB | 43 | Tab and Backtab
THREE | 32 | 3 and #
TWO | 31 | 2 and @
U | 24 | u and U
UP_ARROW | 82 | Move the cursor up
V | 25 | v and V
W | 26 | w and W
WINDOWS | 227 | Labelled with a Windows logo on Windows keyboards
X | 27 | x and X
Y | 28 | y and Y
Z | 29 | z and Z
ZERO | 39 | 0 and )

## Mouse codes

Mouse Code | Value | Function
BACK_BUTTON | 8 | Back mouse button.
FORWARD_BUTTON | 16 | Forward mouse button.
LEFT_BUTTON | 1 | Left mouse button.
MIDDLE_BUTTON | 4 | Middle mouse button.
RIGHT_BUTTON | 2 | Right mouse button.

QuanClick Project Instructions

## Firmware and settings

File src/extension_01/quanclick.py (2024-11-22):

import time
import board
import digitalio
import usb_hid
import random

from adafruit_hid.keyboard import Keyboard
from adafruit_hid.keyboard_layout_us import KeyboardLayoutUS
from adafruit_hid.keycode import Keycode
from adafruit_hid.mouse import Mouse
from adafruit_hid.consumer_control import ConsumerControl
from adafruit_hid.consumer_control_code import ConsumerControlCode

### region configuration
# ==============================================================================================

# Set constants
KEYBOARD_CHAR_DELAY_MIN = 0.03
KEYBOARD_CHAR_DELAY_MAX = 0.06

CCC_PLAY_PAUSE_TOGGLE = 0xB1

# Define the GPIO pins for the buttons
button_pins = [board.GP0, board.GP2, board.GP4, board.GP1, board.GP3, board.GP5]

# Define actions for each button (now starting from 1)
button_actions = {
    # Sends the Keyboard Commands a b c
    1: {"type": "keyboard", "action": [Keycode.A, Keycode.B, Keycode.C]},
    # Types the string "Hello, World!"
    2: {"type": "keyboard_string", "action": "Hello, World!"},
    # Sends the Volume Up special key
    3: {"type": "consumer_control", "action": ConsumerControlCode.VOLUME_INCREMENT},
    # Sends a combination Win+e, to open File Explorer
    4: {"type": "keyboard", "action": [[Keycode.WINDOWS, Keycode.E]]},
    # Moves the mouse 20 units left
    5: {"type": "mouse_move", "action": (-20, 0)},  # Move left
    # Uses a Consumer Control Code direcly to send 0xB1 
    6: {"type": "consumer_control", "action": CCC_PLAY_PAUSE_TOGGLE}
}

### endregion


### region setup
# ==============================================================================================

# Initialize the keyboard, mouse, and consumer control
keyboard = Keyboard(usb_hid.devices)
keyboard_layout = KeyboardLayoutUS(keyboard)
mouse = Mouse(usb_hid.devices)
consumer_control = ConsumerControl(usb_hid.devices)

# Create a list of DigitalInOut objects for each button
buttons = [digitalio.DigitalInOut(pin) for pin in button_pins]

# Initialize a list to store the previous state of each button
previous_button_states = [True] * len(buttons)

# Configure each button as an input with a pull-up resistor
for button in buttons:
    button.switch_to_input(pull=digitalio.Pull.UP)

### endregion


### region functions
# ==============================================================================================

def perform_keyboard_action(action):
    """
    This will send a series of key presses in sequence.

    If the 'action' is a keycode, the keycode will be sent

    If the 'action' is a list of keycodes, the key codes will be sent in sequence

    If the 'action' is a list containing lists, then combination of keycodes will 
    be sent

    Args:
        action: The combination of Keycodes to send 
    """
    if isinstance(action, list):

        for key_code in action:
            if isinstance(key_code, list):
                for code in key_code:
                    keyboard.press(code)
                keyboard.release_all()
            else:
                keyboard.press(key_code)
                keyboard.release(key_code)
    else:
        keyboard.press(action)
        time.sleep(KEYBOARD_CHAR_DELAY_MIN)
        keyboard.release(action)


def perform_keyboard_string(string):
    """
    This will send a string from the virtual keyboard using the layout 
    specified by keyboard_layout

    To avoid buffer issues, and to bypass some intrusion detection 
    software on some platforms: The input string is broken up into individual
    charachters, and sent with a short random delay 

    Args:
        string: The string that should be encoded, and sent to the host
    """
    for char in string:
        keyboard_layout.write(char)
        time.sleep(random.uniform(KEYBOARD_CHAR_DELAY_MIN, KEYBOARD_CHAR_DELAY_MAX))


def perform_mouse_move(movement):
    """Moves the mouse by the specified movemetn"""
    mouse.move(x=movement[0], y=movement[1])

def perform_mouse_click(button):
    """Clicks the specified mouse button"""
    mouse.click(button)


def perform_consumer_control_action(action):
    """
    Sends a ConsumerControl action when 'action' is a specified ConsumerControlCode 
    

    Args:
        action: a ConsumerControlCode action:

        BRIGHTNESS_DECREMENT   BRIGHTNESS_INCREMENT   EJECT       FAST_FORWARD       
        MUTE                   PLAY_PAUSE             RECORD      REWIND             
        SCAN_NEXT_TRACK        SCAN_PREVIOUS_TRACK    STOP        VOLUME_DECREMENT   
        VOLUME_INCREMENT   

        Alternatively:
          Specify a 16-bit consumer control code from:
          https://www.usb.org/sites/default/files/hut1_21_0.pdf#page=118
    """
    consumer_control.send(action)

### endregion

### region main loop
# ==============================================================================================
while True:
    # Iterate through each button
    for button_index, button in enumerate(buttons, start=1):  # Start enumeration from 1
        current_button_state = button.value

        # Check if the button state has changed
        if current_button_state != previous_button_states[button_index - 1]:
            # Update the previous state
            previous_button_states[button_index - 1] = current_button_state

            if current_button_state:  # Button is released (due to pull-up)
                print(f"Button {button_index} is released")

                # Perform the corresponding action
                action_info = button_actions.get(button_index)
                if action_info:
                    action_type = action_info["type"]
                    action = action_info["action"]

                    if action_type == "keyboard":
                        perform_keyboard_action(action)
                    elif action_type == "keyboard_string":
                        perform_keyboard_string(action)
                    elif action_type == "mouse_move":
                        perform_mouse_move(action)
                    elif action_type == "mouse_click":
                        perform_mouse_click(action)
                    elif action_type == "consumer_control":
                        perform_consumer_control_action(action)

            else:  # Button is pressed
                print(f"Button {button_index} is pressed")

    # Add a small delay to prevent excessive CPU usage
    time.sleep(0.01)

### endregion

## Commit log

2024-11-22 new instructions that I think contain everything that was missing from yesterday changed the "code.py" default back to quanclick.py to avoid back confusion I have amended the instructions to change c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
    [quanclick.py]
2024-11-22 change naming to quanclick.py, and fix references. Add extension example
    [quanclick.py]
2024-11-24 Added parts list with example suppliers Added CAD files
    [QuanClick_Base.stl, QuanClick_LetA.stl, QuanClick_LetC.stl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]
